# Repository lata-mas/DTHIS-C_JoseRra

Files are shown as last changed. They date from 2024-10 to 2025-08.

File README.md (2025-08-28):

# DTHIS-C

Este dispositivo se realizó gracias al apoyo del proyecto UNAM-PAPIIT IT103023.

El **DTHIS-C** (Dispositivo de Temperatura, Humedad, Iluminación y Sonido de Campaña) está diseñado para medir y evaluar condiciones ambientales tanto en interiores como en exteriores. Su principal ventaja es su portabilidad y su capacidad para adquirir y almacenar datos, haciéndolo ideal para campañas en sitios remotos o situaciones que requieren movilidad.

## Variables que mide el DTHIS-C

El dispositivo está equipado para medir una amplia gama de variables, tales como:

- **Temperatura del aire** a diferentes alturas:
  1. 0.1 m
  2. 0.6 m
  3. 1.1 m
  4. 1.7 m
- **Temperatura radiante**
- **Humedad relativa**
- **Velocidad del viento**
- **Concentración de CO₂**
- **Mapas de luminancia** para evaluar la iluminación
- **Deslumbramiento**
- **Niveles de sonido**

---

## Composición del DTHIS-C

El dispositivo se compone de los siguientes sensores y componentes electrónicos:

| **Sensor** | **Variable** | **Cantidad** | **Comunicación** | **Microcontrolador** | **Acondicionador de señal**  |
|---|---|---|---|---|---|
| Termopar tipo T | Temperatura Ambiente | 4 | SPI | Arduino UNO WiFi Rev2 | PWFusion SEN-30007 MAX31856	 |
| TPF1/E-20 PT1000 | Temperatura Radiante | 1 | SPI | Arduino UNO WiFi Rev2 | Adafruit PT1000 RTD-MAX31865 |
| Wind Sensor Rev P6 | Velocidad del Viento		 	 | 1 | ADC | Arduino UNO WiFi Rev2 |				 				 |
| SCD30 Sensirion | CO₂ y Humedad Relativa | 1 | I2C | Raspberry Pi 4 |				 				 |
| 5MP OV5647 Wide Angle Fisheye Camera | Luminancia | 1 | CSI | Raspberry Pi 4 |				 				 |
| Micrófono ambiental USB | Sonido | 1 | USB | Raspberry Pi 4 | |

---

## Elementos del repositorio
 
-  #### En [**CAD**](https://github.com/lata-mas/DTHIS-C_JoseRra/tree/main/CAD) encuentra
	-  Planos CAD
	-  Archivos de diseño CAD
	-  Archivos STL para impresión 3D

 - #### En [**Diagramas**](https://github.com/lata-mas/DTHIS-C_JoseRra/tree/main/Diagramas) encuentra
	- Pictograma de conexión
	- Esquemático de conexión

 - #### En [**Manuales**](https://github.com/lata-mas/DTHIS-C_JoseRra/tree/main/Manuales) encuentra
	-  Manual de operación
   	-  Fichas técnicas o datasheet de los sensores y componentes utilizados

 -  #### En [**Materiales**](https://github.com/lata-mas/DTHIS-C_JoseRra/tree/main/Materiales) encuentra
	-  Lista de materiales y costos

 -  #### En [**Scripts**](https://github.com/lata-mas/DTHIS-C_JoseRra/tree/main/Scripts) encuentra
	- Códigos completos y documentados
	- Librerías a utilizar

---

## Participantes del proyecto

El equipo responsable del desarrollo y construcción del DTHIS-C está conformado por los siguientes integrantes:

| **Nombre** | **Instituto/Organización** | **Email** |
|---|---|---|
| Guillermo Barrios del Valle  | IER-UNAM | gbv@ier.unam.mx |
| Guillermo Ramírez Zúñiga | IER-UNAM | guraz@ier.unam.mx |
| Jorge Luis Méndez Reyna | IER-UNAM | merejo@ier.unam.mx |
| Julio César Landa López | IER-UNAM | jclalo@ier.unam.mx |
| José Ramón Hernández Aguilar | IER-UNAM | jrha@ier.unam.mx |
| Pedro Ayala Espinosa	 | IER-UNAM | aepe@ier.unam.mx |
| Debra Paola López Domínguez  | | dpld@ier.unam.mx |
| Edgar Gallardo Pérez | | |
| José William Escobar Escobar | | |

---

> [!Tip]
> Este repositorio está diseñado para simplificar el desarrollo y uso del dispositivo **DTHIS-C**. Con su uso, podrás acceder a múltiples recursos clave para su implementación y operación eficiente:

### 1. Uso de sensores
Cada sensor integrado en el DTHIS-C tiene su propio directorio en el repositorio, dentro de los cuales encontrarás:
- **Indicaciones** para una correcta implementación.
- **Código funcional** específico para cada sensor.

### 2. Integración con ThingsBoard
El repositorio incluye un archivo **main** que recopila las mediciones de todos los sensores y las envía a la plataforma **ThingsBoard** mediante el protocolo **MQTT**. Esto permite la monitorización en tiempo real de las variables.

### 3. Manual de uso y ensamblaje
Además, el repositorio ofrece un manual detallado que cubre:
- **Esquemas de conexión** y **diagramas eléctricos**.
- **Instrucciones paso a paso** para el ensamblaje del DTHIS-C.
 
Este repositorio es útil tanto para trabajar con sensores de forma individual como para la construcción completa del dispositivo DTHIS-C.

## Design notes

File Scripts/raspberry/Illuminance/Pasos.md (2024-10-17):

# Configuración de la cámara en Raspberry Pi 4 y captura de fotos

### 1. Conectar la cámara
- Apaga la Raspberry Pi.
- Conecta la cámara al puerto CSI.
- Asegúrate de que la cinta esté bien conectada, con la parte metálica hacia el conector del puerto.

### 2. Actualizar el sistema
```bash
sudo apt update && sudo apt upgrade
```

### 3. Reiniciar Raspberry Pi
```bash
sudo reboot
```

### 4. Tomar una foto
```bash
rpicam-still -o imagen.jpg
```

---

# Instalación de Radiance 

### 1. Instala las dependencias necesarias:
```bash
sudo apt install csh make gcc g++ libx11-dev tcl tk
```

### 2. Descarga Radiance y el soporte adicional:
```bash
wget https://www.radiance-online.org/software/snapshots/radiance-HEAD.tgz
wget https://www.radiance-online.org/download-install/radiance-source-code/latest-release/rad5R4supp.tar.gz
```

### 3. Descarga `config.guess` y `config.sub`:
```bash
wget -O config.guess 'http://git.savannah.gnu.org/gitweb/?p=config.git;a=blob_plain;f=config.guess;hb=HEAD'
wget -O config.sub 'http://git.savannah.gnu.org/gitweb/?p=config.git;a=blob_plain;f=config.sub;hb=HEAD'
```

### 4. Descomprime los archivos descargados:
```bash
tar -xvzf radiance-HEAD.tgz
tar -xvzf rad5R4supp.tar.gz
```

### 5. Copia `config.sub` y `config.guess` al directorio `px/tiff/`:
```bash
cp config.sub ray/src/px/tiff/
cp config.guess ray/src/px/tiff/
```

### 6. Entra en el directorio `ray/` y compila la librería:
```bash
cd ray/
sudo ./makeall library
```
- Cuando se pregunte **"Where do you want the library files [/usr/local/lib/ray]?"**, puedes presionar `Enter` para aceptar la ruta predeterminada. Luego, cuando te pregunte **"Install library files now [n]?"**, responde `y` (sí).

### 7. Agrega la siguiente línea al archivo `.profile` para configurar el `RAYPATH`:
Abre el archivo `.profile`:
```bash
nano ~/.profile
```
Agrega las siguientes líneas al final del archivo:
```bash
RAYPATH=.:/usr/local/lib/ray
export RAYPATH
```
Guarda y cierra el archivo presionando `Ctrl + O`, `Enter`, y luego `Ctrl + X`.

### 8. Compila todo el proyecto:
Ejecuta el siguiente comando:
```bash
sudo ./makeall install
```
- Cuando te pregunte **"What is your preferred editor [vi]?"**, puedes simplemente presionar `Enter` para aceptar la opción predeterminada (vi)
- Cuando se te pregunte **"Where do you want the executables [/usr/local/bin]?"**, presiona `Enter` para aceptar la ruta predeterminada.
- Tras haber presionado `Enter` se mostrará la licencia de software de Radiance, presiona `q` para salir de la visualización y luego responde `y` (sí) para aceptar los términos. Selecciona `2` para Linux cuando se te pregunte por el tipo de sistema.
- Cuando se te pregunte **"Do you want to change it?"**, presiona `n` (no) para continuar con la configuración predeterminada.

### 9. Verifica la instalación:
Para asegurarte de que Radiance se haya instalado correctamente, ejecuta:
```bash
which rad
```
Esto debería devolver la ruta del ejecutable rad si la instalación fue exitosa.

---

# Configuración adicional

### 1. Instalar raw2hdr 
Descarga el software *raw2hdr* desde [aquí](http://www.anyhere.com/gward/pickup/raw2hdr.tgz) (debería descargarse si arrastras el enlace hacia otra pestaña). 
- Descomprime el archivo descargado con el siguiente comando, aunque igualmente puedes descomprimirlo sin la necesidad de acudir a la terminal:
  ```bash
  tar -xvzf raw2hdr.tgz
  ```
- Tras ello se creará la carpeta `raw2hdr` en tu **home** con los siguientes archivos ejecutables:
  - dcraw (Descartar)
  - exiftool (Descartar)
  - hdrgen (Descartar)
  - raw2hdr
- Para que raw2hdr funcione con imágenes DNG, accede al archivo ejecutable `raw2hdr` y agrega lo siguiente a la configuración del array `@exiftags` :
  ```bash
  -ISO -ApertureValue>FNumber -FNumber=2.6
  ```
- Finalmente para utilizar los comandos de los programas desde cualquier ubicación, los archivos ejecutables deben encontrarse en `/usr/local/bin/`:
  ```bash
  sudo cp exiftool raw2hdr /usr/local/bin/
  ```

### 2. Es necesario instalar los programas `hdrgen`, `dcraw` y `exiftool` para que `raw2hdr` se pueda compilar correctamente.  

#### hdrgen 
Puedes descargar *hdrgen* desde [aquí](http://anyhere.com/gward/pickup/hdrgen_AMDRaspian.tar.gz) (al arrastrar el enlace a otra pestaña se inicia la descarga).  
- Descomprime el archivo descargado preferentemente sin acudir a la terminal.
- Tras ello se creará la carpeta `hdrgen_AMDRaspian` en tu **home** con los siguientes archivos ejecutables:
  - hdrcvt
  - hdrgen
- Copia los archivos ejecutables hacia `/usr/local/bin/`:
  ```bash
  sudo cp hdrcvt hdrgen /usr/local/bin/
  ```

#### dcraw
Para instalar *dcraw*, asegúrate de ejecutar el comando:
```bash
sudo apt-get install dcraw
```

#### exiftool
Para descargar *exiftool*, ejecuta la siguiente línea:
```bash
wget https://exiftool.org/Image-ExifTool-12.97.tar.gz
```
- Una vez descargado, descomprime el archivo y accede al directorio:
  ```bash
  gzip -dc Image-ExifTool-12.97.tar.gz | tar -xf -
  cd Image-ExifTool-12.97
  ```
- Procede a instalarlo:
  ```bash
  perl Makefile.PL
  sudo make install
  ```

### 3. Instalar bibliotecas de fuentes para visualizar imágenes
Finalmente, necesitas descargar una biblioteca de fuentes para poder visualizar las imágenes. Si no tienes las fuentes instaladas, usa el siguiente comando:
```bash
sudo apt-get install xfonts*
```

---

# Creación de un script de shell con vim

### 1. Abre `vim` y crea un nuevo archivo de script:
```bash
vim script.sh
```

### 2. Entra en el **modo de inserción** presionando la tecla `i`.

### 3. Escribe el contenido del script:
```bash
#!/bin/bash
echo "Hola, este es mi primer script!"
```

### 4. Una vez que hayas terminado de escribir el script, presiona `Esc` para salir del **modo de inserción**.

### 5. Guarda el archivo y sal de `vim` escribiendo `:wq` y presionando `Enter`. Esto significa:
- `w` para guardar el archivo.
- `q` para salir de `vim`.

### 6. Haz el script ejecutable con el siguiente comando:
```bash
chmod +x script.sh
```

### 7. Ejecuta el script:
```bash
./script.sh
```

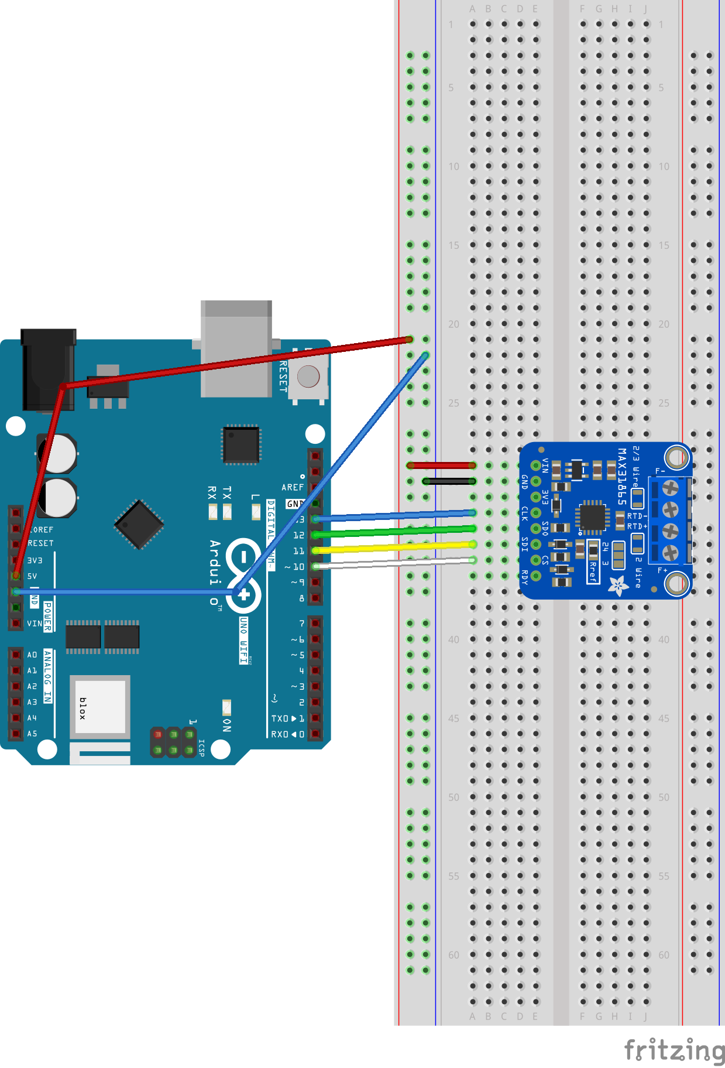
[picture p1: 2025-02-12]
Diagramas/Pictogramas/pt1000_bb.png

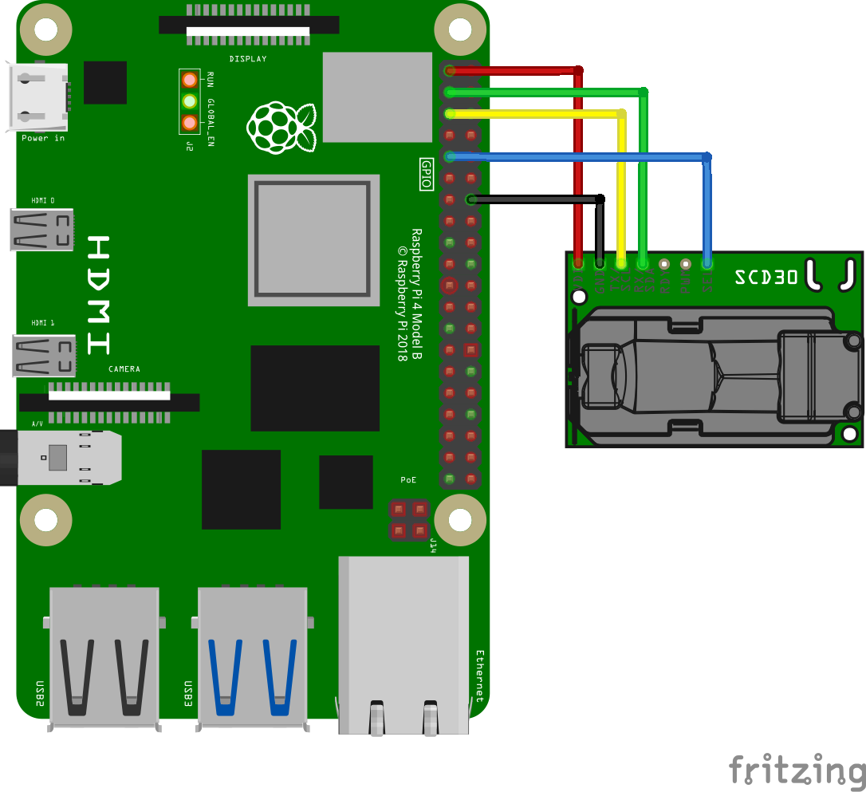
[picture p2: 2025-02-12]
Diagramas/Pictogramas/scd30_bb.png

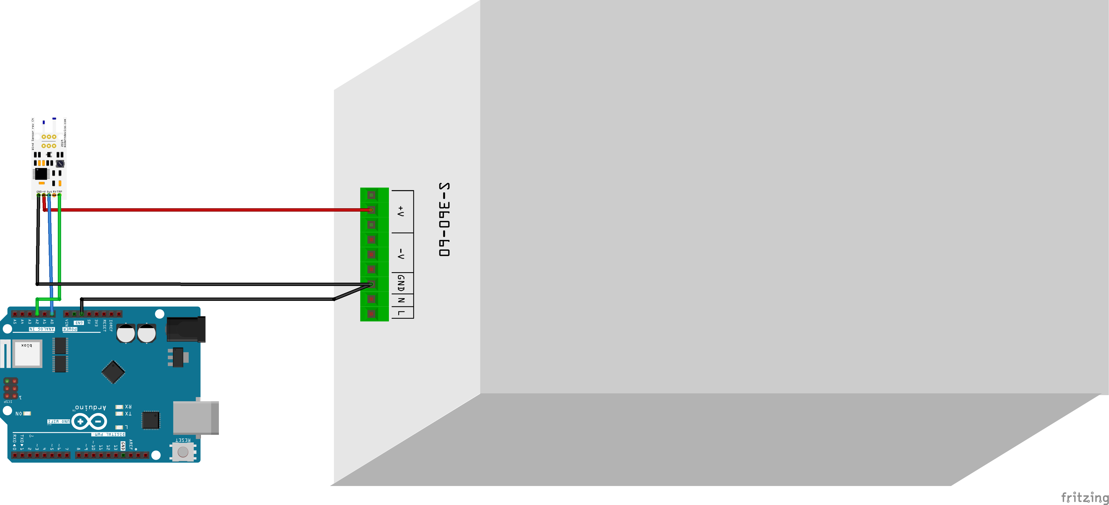
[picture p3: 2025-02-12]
Diagramas/Pictogramas/windsensor_bb.png

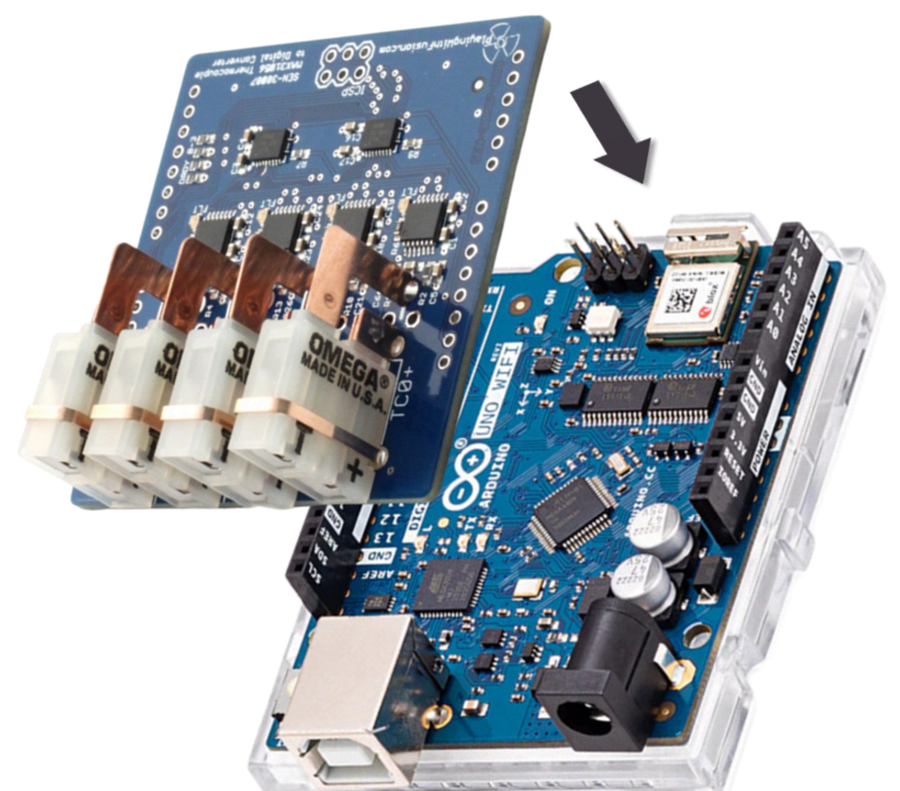
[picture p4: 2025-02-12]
Diagramas/Pictogramas/sen30007_bb.png

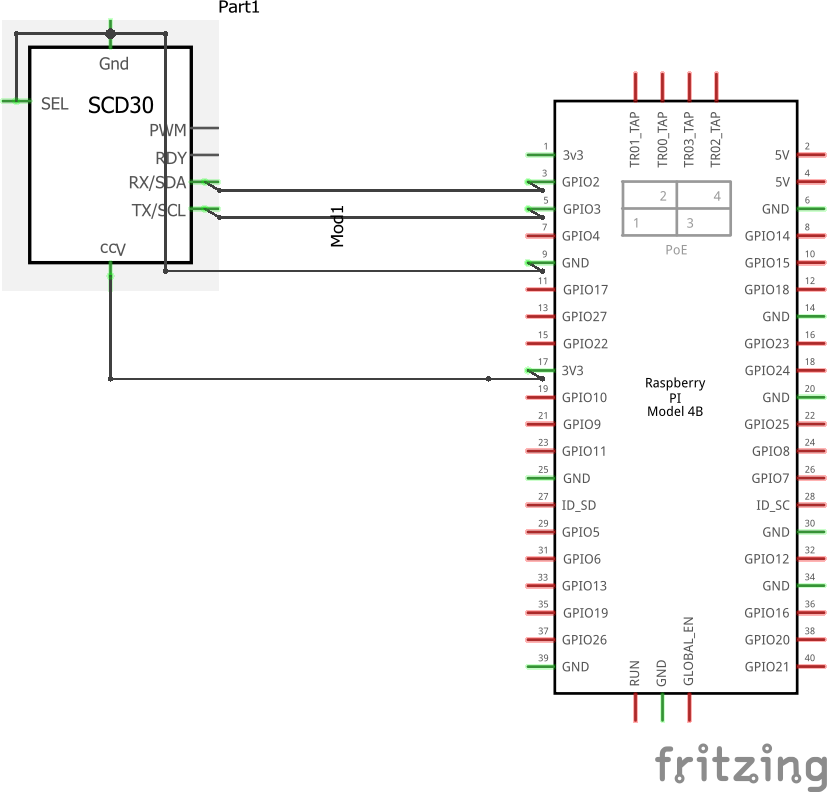
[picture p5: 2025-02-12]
Diagramas/Esquematicos/scd30_esquematico.png

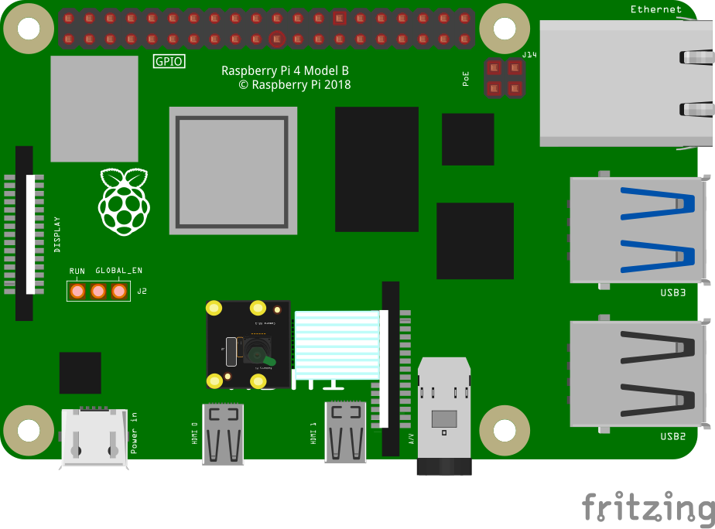
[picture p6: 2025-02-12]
Diagramas/Pictogramas/camera_bb.png

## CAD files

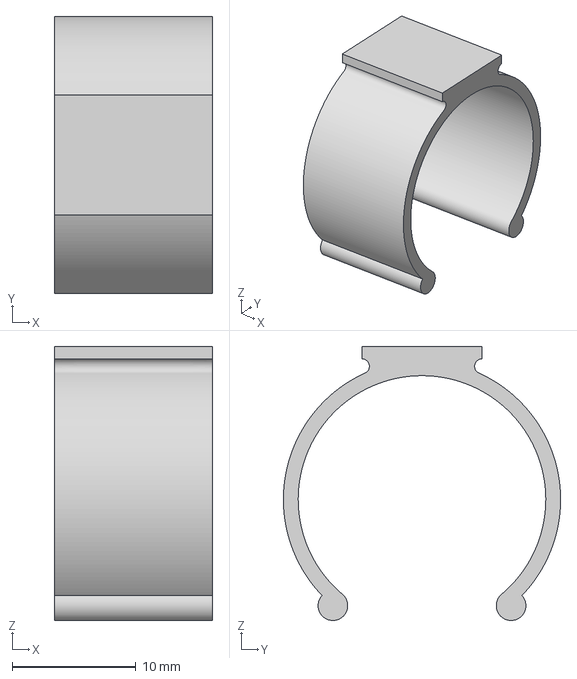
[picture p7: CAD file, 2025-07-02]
CAD/3MF/Wind_Sensor/WS_Ring_Horizontal_3cuartes_inch.3mf
12.8 x 22.4 x 22.1 mm

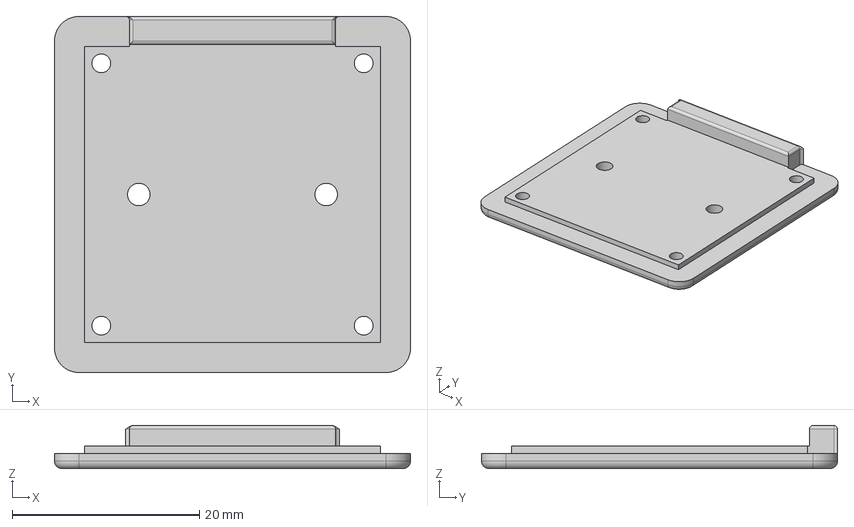
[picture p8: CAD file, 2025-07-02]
CAD/STEP/Camera/Camera_Cover.step
38.0 x 38.0 x 4.60 mm
Camera
Cam_Case
Cam_Cover

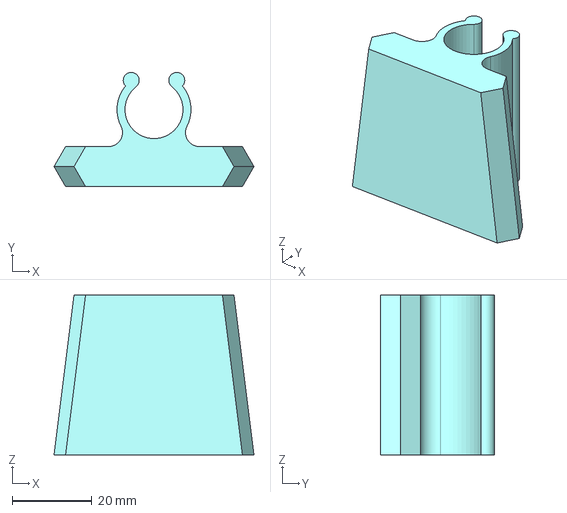
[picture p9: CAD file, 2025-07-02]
CAD/STEP/Case/Ring_Bottom.step
50.0 x 28.5 x 40.0 mm

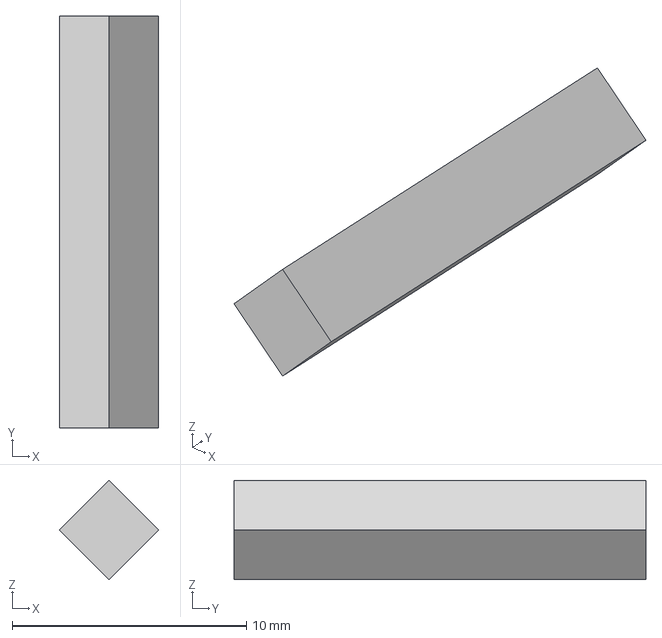
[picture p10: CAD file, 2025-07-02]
CAD/STEP/Power_Supply_Case/4xPowerSupply_Pin.step
4.24 x 17.6 x 4.24 mm

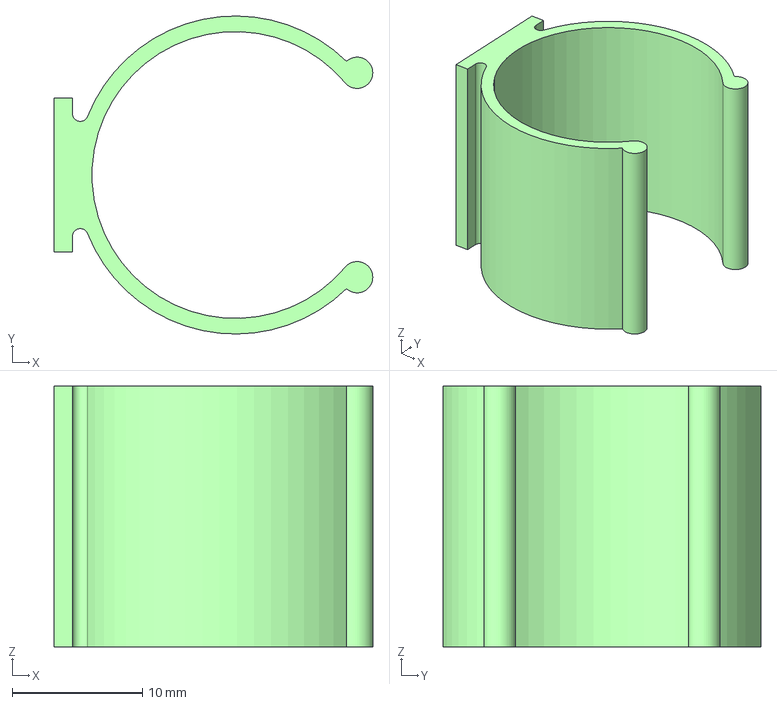
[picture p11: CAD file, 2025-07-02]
CAD/STEP/TRad/Ring_Vertical_TRad_3quarters_inch.step
24.4 x 24.4 x 20.0 mm

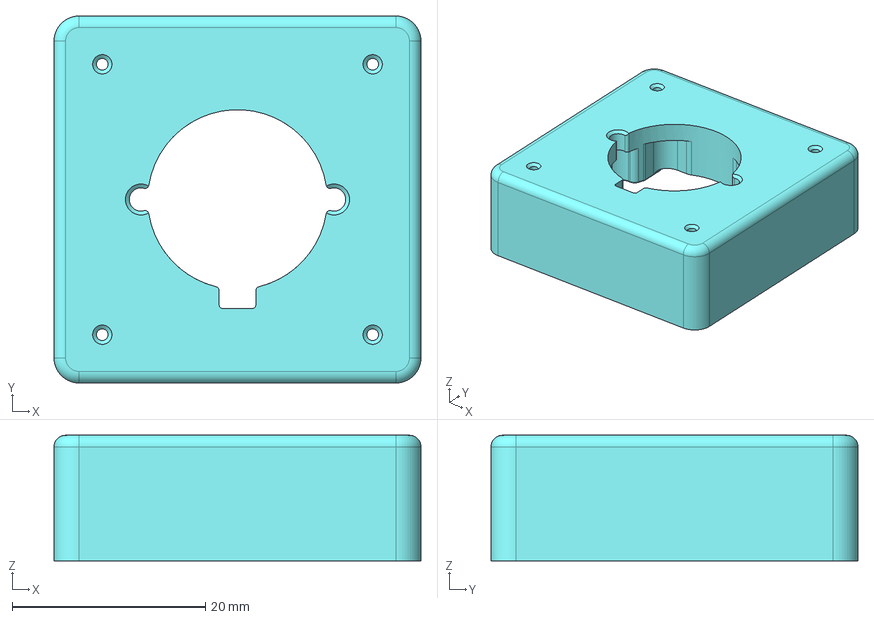
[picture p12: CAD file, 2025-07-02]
CAD/STEP/Camera/Camera_Case.step
38.0 x 38.0 x 13.0 mm
Camera
Cam_Case
Cam_Cover

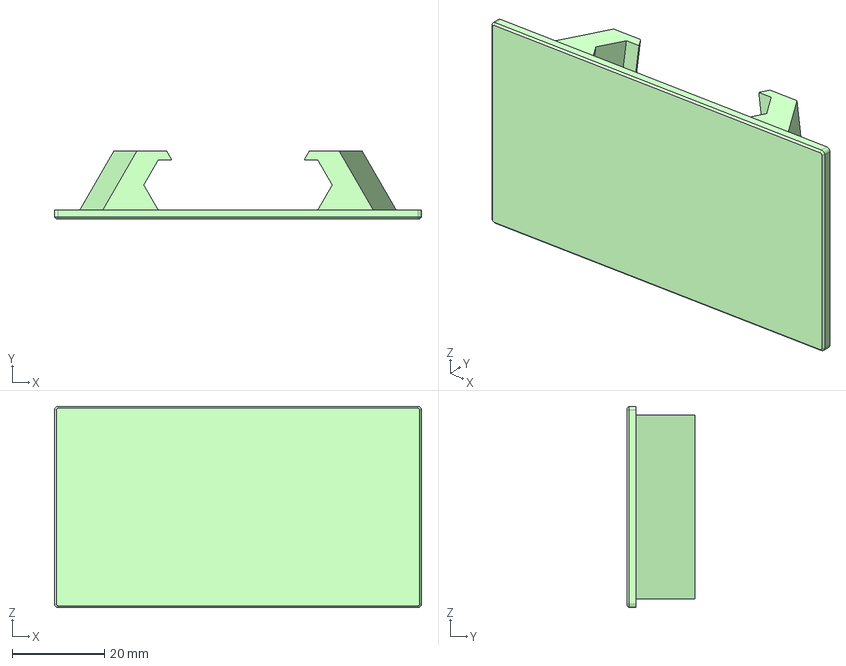
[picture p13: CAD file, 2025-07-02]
CAD/STEP/Case/Hook_Bottom.step
79.7 x 14.8 x 43.7 mm

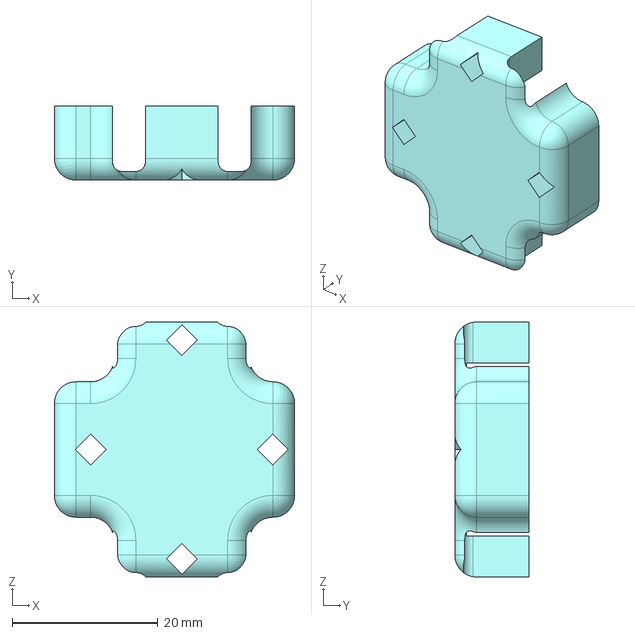
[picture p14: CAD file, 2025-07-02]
CAD/STEP/Power_Supply_Case/PowerSupply_Cover.step
33.0 x 10.2 x 35.0 mm

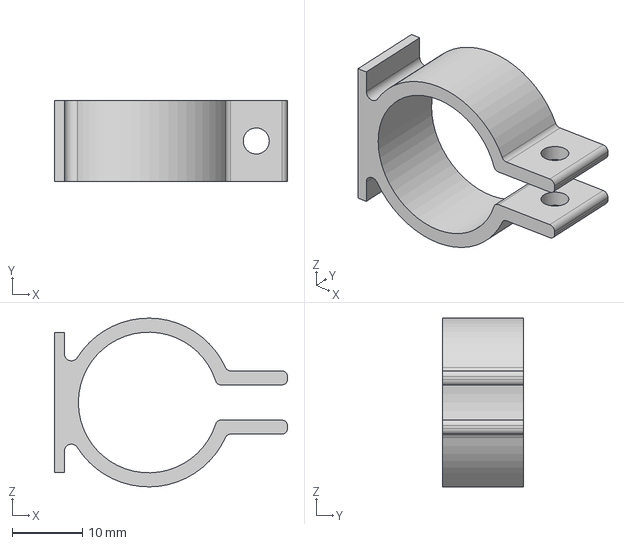
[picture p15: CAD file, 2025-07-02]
CAD/STEP/TRad/Ring_Horizontal_TRad_3quarters_inch.step
33.1 x 11.5 x 24.0 mm

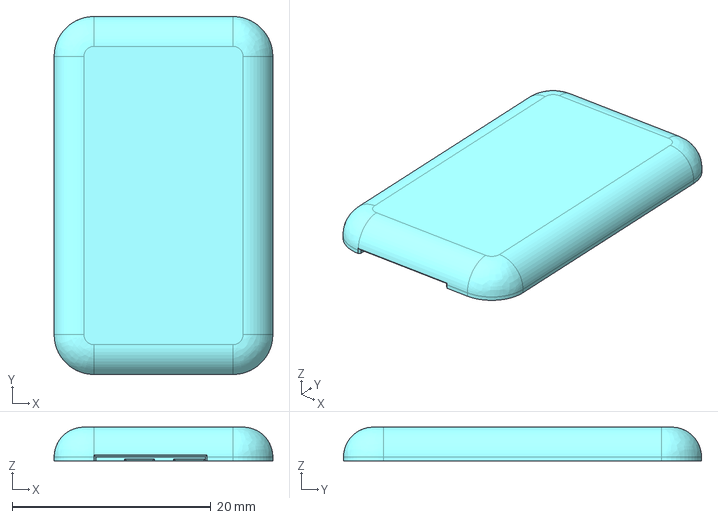
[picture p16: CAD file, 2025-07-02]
CAD/STEP/Wind_Sensor/WS_Cover.step
22.0 x 36.0 x 3.40 mm

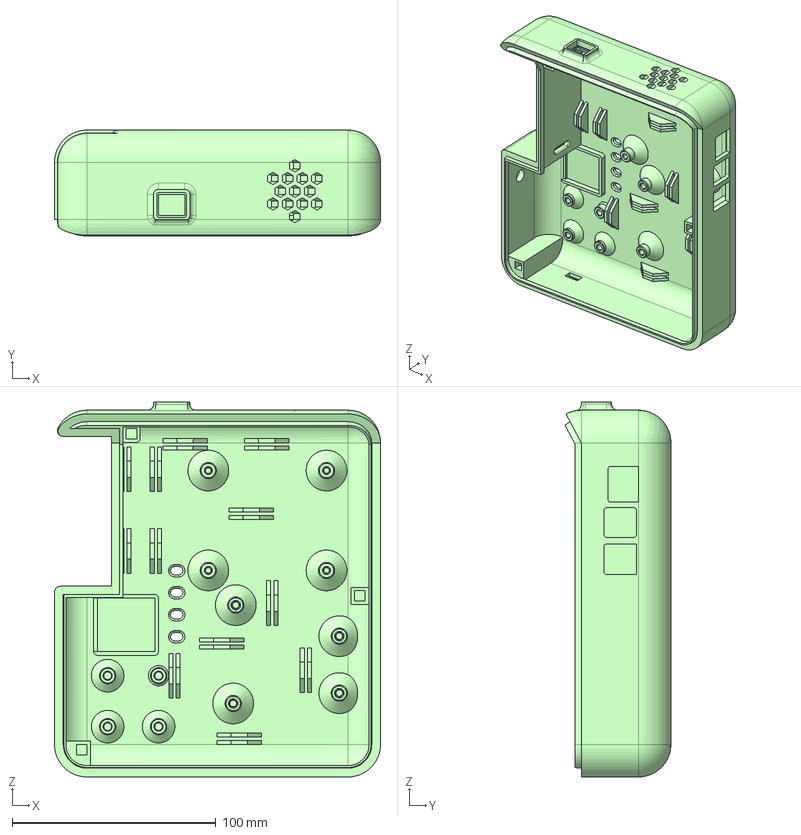
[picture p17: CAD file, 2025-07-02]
CAD/STEP/Case/Case.step
160.0 x 52.0 x 184.0 mm

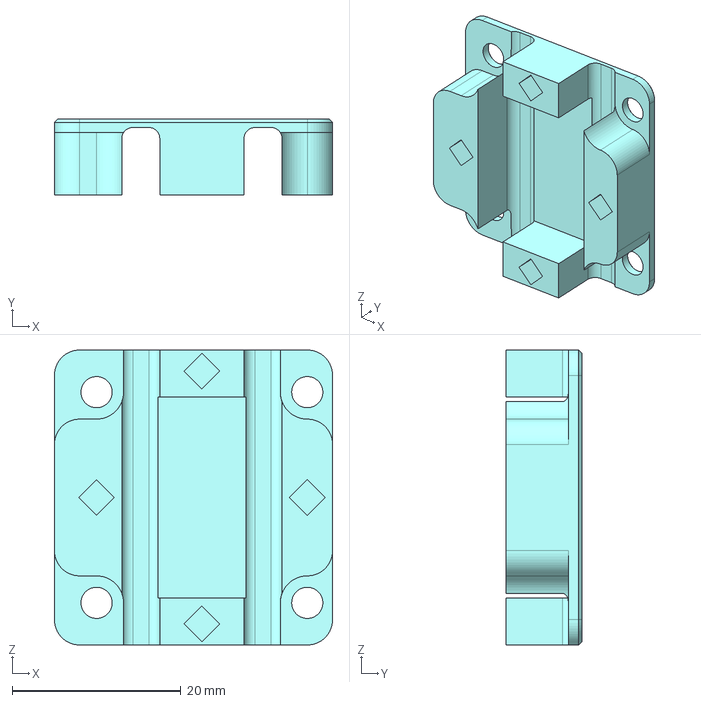
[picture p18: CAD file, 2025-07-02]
CAD/STEP/Power_Supply_Case/Power_Supply_Case.step
33.0 x 9.00 x 35.0 mm

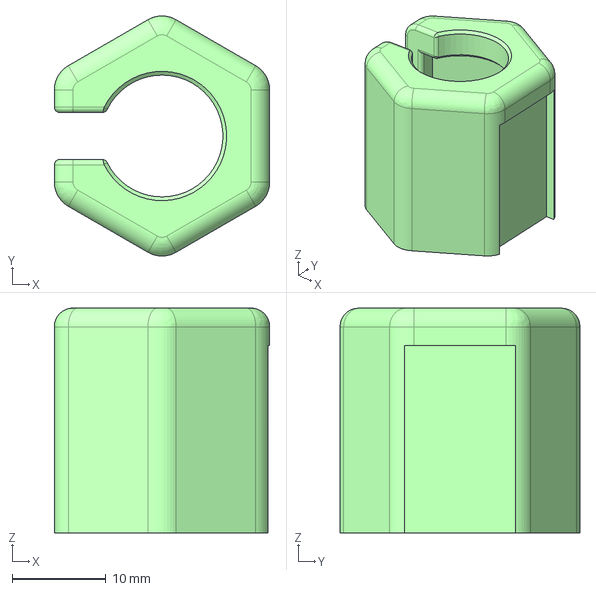
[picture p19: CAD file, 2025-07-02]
CAD/STEP/TRad/TRad_Support.step
23.0 x 25.6 x 24.0 mm

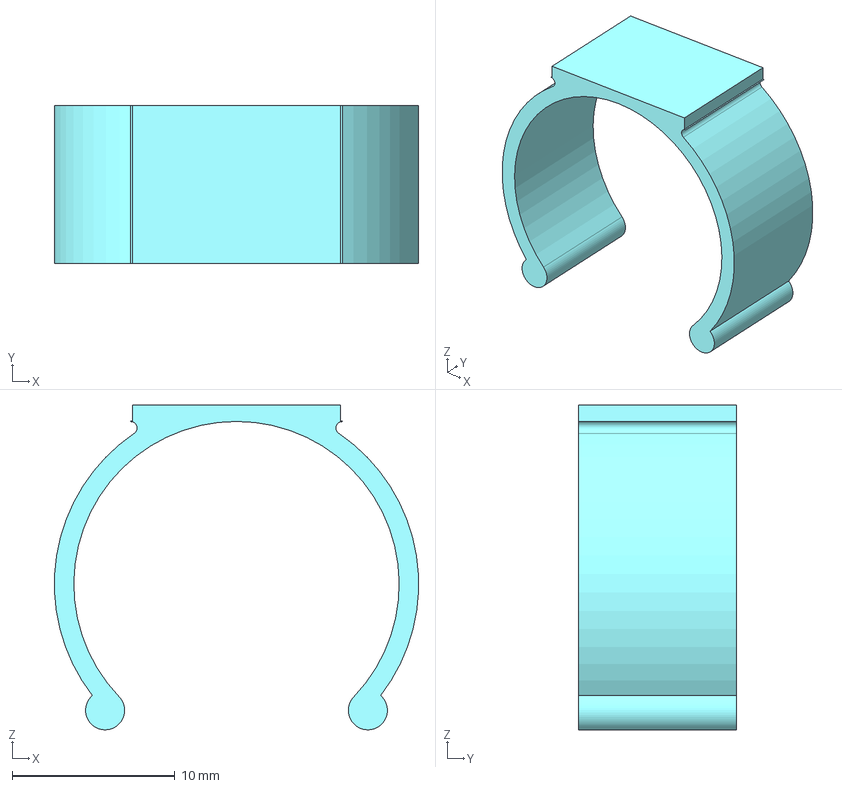
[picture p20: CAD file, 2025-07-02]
CAD/STEP/Wind_Sensor/WS_Ring_Vertical_3quarters_inch.step
22.4 x 9.70 x 20.0 mm

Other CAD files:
CAD/STEP/Wind_Sensor/WS_Ring_Horizontal_3quarters_inch.step
CAD/STEP/Case/Ring_Top.step
CAD/STEP/Wind_Sensor/WS_Case.step
CAD/STEP/Case/Cover.step
CAD/3MF/Camera/Camera_Case.3mf
CAD/3MF/Camera/Camera_Cover.3mf
CAD/3MF/Case/Case.3mf
CAD/3MF/Case/Cover.3mf
CAD/3MF/Case/Hook_Bottom.3mf
CAD/3MF/Case/Hook_Top.3mf
CAD/3MF/Case/Ring_Bottom.3mf
CAD/3MF/Case/Ring_Top.3mf
CAD/3MF/Power_Supply_Case/4xPowerSupply_Pin.3mf
CAD/3MF/Power_Supply_Case/PowerSupply_Case.3mf
CAD/3MF/Power_Supply_Case/PowerSupply_Cover.3mf
CAD/3MF/TRad/Ring_Horizontal_TRad_3quarters_inch.3mf
CAD/3MF/TRad/Ring_Vertical_TRad_3quarters_inch.3mf
CAD/3MF/TRad/TRad_Support.3mf
CAD/3MF/Wind_Sensor/WS_Case.3mf
CAD/3MF/Wind_Sensor/WS_Cover.3mf
CAD/3MF/Wind_Sensor/WS_Ring_Vertical_3quarters_inch.3mf
CAD/STEP/Case/Hook_Top.step
CAD/STL/Camera/Camera_Case.stl
CAD/STL/Camera/Camera_Cover.stl
CAD/STL/Case/Case.stl
CAD/STL/Case/Cover.stl
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

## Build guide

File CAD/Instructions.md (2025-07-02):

## Instructions to print the pieces

- Set the pieces flat whenever possible (print hooks and case rings as they are).  
- Infill of 10% gyroid or cubic and 4 perimeters are recommended for fast processing times.  
- Printing with UV‑resistant filament is recommended (ASA).  

---

## List of extra hardware required for mounting and power supply

### Electronic hardware

- 1 × 10 W 5 V DC buck converter  
- 2 × banana plug binding post socket  
- 1 × XT30 female connector  
- 1 × 4‑channel 5‑pin perfboard  
- 4 × 5 × 2.54 mm pin headers  
- 1 × 5 V fan  

---

## Mounting hardware

### SCD30

- 4 × 10 mm M2 nylon standoffs  
- 4 × M2 × 6 mm nylon screws  
- 4 × M2 × 3 mm brass inserts  

### Raspberry Pi 4

- 4 × M2 × 6 mm brass inserts  
- 4 × M2 × 6 mm nylon screws  

### Arduino Uno

- 4 × 6 mm M3 nylon standoffs  
- 4 × M3 × 6 mm nylon screws  
- 4 × M3 × 6 mm brass inserts  

### Fan

- 4 × M3 × 4 mm brass inserts  
- 4 × M3 × 8 mm screws  

### Thermocouple

- 2 × M2 × 3 mm brass inserts  
- 2 × M2 × 4 mm nylon standoffs  
- 2 × M2 × 6 mm screws  

### Power supply

- 4 × M3 × 6 mm brass inserts  
- 4 × M3 × 6 mm nylon screws  

### Magnets

- 6 × 5 mm × 5 mm × 5 mm N52 neodymium magnets  

*Created at IER‑UNAM by Joserra & Aerofal (2025)*

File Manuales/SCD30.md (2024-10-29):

# Configuración del SCD30 en Raspberry Pi 4

### 1. Ensamblar el circuito
Para la conexión del sensor SCD30, se requiere una Raspberry Pi 4 Model B y los cables de conexión (jumpers) incluidos con el sensor, que permiten la conexión directa al microcontrolador. Las conexiones deben realizarse de acuerdo con el siguiente diagrama:
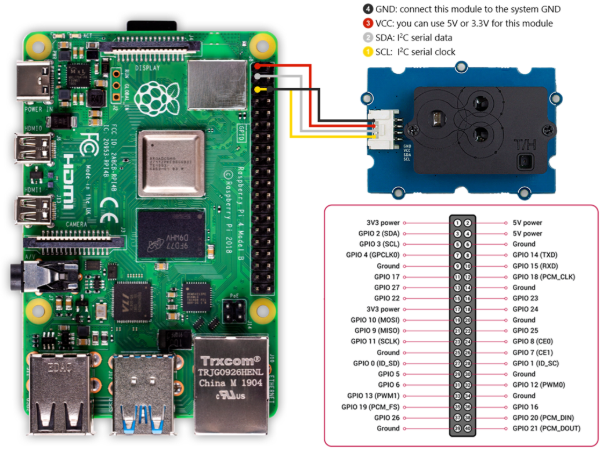
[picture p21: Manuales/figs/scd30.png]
SCD30


### 2. Crear script de Python
El script [scd30.py](https://github.com/lata-mas/DTHIS-C_JoseRra/blob/main/Scripts/Raspberry/scd30.py) inicializa el sensor `SCD30` y obtiene lecturas de la `concentración de CO2`, `temperatura` y `humedad relativa` para devolverlos como una tupla (CO2, T, HR) al final.

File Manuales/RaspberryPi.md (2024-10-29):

# Configuración general de la Raspberry Pi 4

### 1. Habilitar comunicaciones 
Antes de tratar de inicializar cualquier tipo de sensor, se deberán habilitar las siguientes comuncionaciones:
- SPI
- I2C
- Serial Port
- 1-Wire

Para acceder a la configuración, se debe ejecutar el siguiente comando en la terminal:
```bash
sudo raspi-config
```
1. Dentro del menú, es necesario dirigirse al apartado `Interface Options`.
2. Habilitar uno por uno: **SPI**, **I2C**, **Serial Port**, **1-Wire**.
3. Al finalizar se reiniciará la Raspberry.

### 2. Crear un ambiente virtual
Dentro de la terminal, se creará un directorio que albergue los ambientes virtuales, así mismo dentro de dicho folder, se creará el ambiente ejecutando las siguientes líneas:
```bash
mkdir venvs
cd venvs
python -m venv dthis-c
```

Tras haberse creado, debe activarse con el siguiente comando:
```bash
source venvs/dthis-c/bin/activate
```

### 3. Instalar bibliotecas 
Las bibliotecas necesarias para ejecutar los scripts de Python de cada sensor que forma parte del DTHIS-C se pueden obtener instalando el archivo [requirements.txt](https://github.com/lata-mas/DTHIS-C_JoseRra/blob/main/Scripts/Raspberry/requirements.txt) dentro del entorno virtual.

1. Activa el entorno virtual:
```bash
source venvs/dthis-c/bin/activate
```
2. Instala las dependencias desde el archivo `requirements.txt`:
```bash
python -m pip install -r requirements.txt
```

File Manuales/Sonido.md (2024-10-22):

# Configuración del micrófono en Raspberry Pi 4

### 1. Conectar el micrófono
- Apaga la Raspberry Pi.
- Conecta el micrófono a un puerto USB.

### 2. Instalar paqueterías
```bash
sudo apt update
sudo apt install alsa-utils
sudo apt install sox libsox-fmt-all
```

### 3. Comprobar micrófono
Para identificar a que puerto está conectado el micrófono, ejecuta el siguiente comando:
```bash
arecord -l
```
Se desplegará lo siguiente:

Terminal

En este caso `card 3` es el puerto al que está conectado el micrófono, por lo tanto al ejecutar el comando para la captura de audio, se deberá definir `plughw:3,0`.

### 4. Grabar audio
Para grabar un audio se ejecuta el siguiente comando:
```bash
arecord -D plughw:3,0 -f cd -t wav -d 15 -r 44100 audio.wav
```

---

# Creación de un programa para la obtención de datos de los audios

### 1. Crear scripts acorde a las funciones 
- [grabar.sh](https://github.com/lata-mas/DTHIS-C_JoseRra/blob/main/Scripts/Raspberry/Sonido/grabar.sh): Graba 15 segundos de audio en calidad CD. 
- [dBmax.sh](https://github.com/lata-mas/DTHIS-C_JoseRra/blob/main/Scripts/Raspberry/Sonido/dBmax.sh): Extrae la amplitud máxima del archivo de audio.
- [dBmin.sh](https://github.com/lata-mas/DTHIS-C_JoseRra/blob/main/Scripts/Raspberry/Sonido/dBmin.sh): Extrae la amplitud mínima del archivo de audio.
- [rms.sh](https://github.com/lata-mas/DTHIS-C_JoseRra/blob/main/Scripts/Raspberry/Sonido/rms.sh): Extrae la amplitud RMS, una medida de la potencia promedio del audio.

### 2. Crear un ejecutable para correr todos los scripts
Para evitar que la Raspberry Pi falle por sobrecarga de procesos, se creará un archivo ejecutable `.e` que ejecutará los scripts secuencialmente, asegurando que no haya conflictos entre las instrucciones. Es fundamental especificar la ruta completa del directorio y activar el entorno virtual antes de ejecutar el script que envía la información a ThingsBoard. 

El archivo se crea de la siguiente manera:
```bash
vim executable.e
```

Y su contenido debe ser el siguiente:
```bash
/home/hdeza/Sonido/grabar.sh
/home/hdeza/Sonido/dBmax.sh
/home/hdeza/Sonido/dBmin.sh
/home/hdeza/Sonido/rms.sh
/home/hdeza/venvs/dthis-c/bin/python3 /home/hdeza/dthis/scripts/sound.py
```

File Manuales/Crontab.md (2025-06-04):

# Configuración de crontab en Raspberry Pi

Para automatizar la ejecución periódica de los scripts del DTHIS-C, se utiliza `cron` y el archivo `crontab`. A continuación se describe el proceso de configuración paso a paso.

---

### 1. Hacer los scripts ejecutables

Antes de agendar cualquier tarea en `crontab`, asegúrate de que todos los archivos que deben ejecutarse directamente tengan permisos de ejecución. Por ejemplo, desde la terminal de tu Raspberry Pi:

```bash
chmod +x /home/dthisc/dthis-c/scd30.py
chmod +x /home/dthisc/dthis-c/sound/executable.e
chmod +x /home/dthisc/dthis-c/sonido.py
chmod +x /home/dthisc/dthis-c/illuminance/createHDR.sh
chmod +x /home/dthisc/dthis-c/iluminancia.py
```

### 2. Verificar el contenido actual de crontab

Para revisar las entradas existentes en el crontab del usuario, ejecuta:

```bash
crontab -l
```

### 3. Editar el crontab
Para agregar o modificar las tareas programadas, abre el editor de crontab:

```bash
crontab -e
```

En el editor que se abra (normalmente nano o vim), pega las siguientes líneas al final del archivo:

```bash
# Ejecutar scd30.py cada minuto
* * * * * /bin/bash -c 'source /home/dthisc/venvs/dthisc/bin/activate && /home/dthisc/venvs/dthisc/bin/python3 /home/dthisc/dthis-c/scd30.py' >> /home/dthisc/dthis-c/scd30.log 2>&1

# Ejecutar sonido (ejecutable) cada 2 minutos
*/2 * * * * /home/dthisc/dthis-c/sound/executable.e >> /home/dthisc/dthis-c/sound/errores_e.log 2>&1

# Ejecutar sonido.py cada 2 minutos
*/2 * * * * /bin/bash -c 'source /home/dthisc/venvs/dthisc/bin/activate && /home/dthisc/venvs/dthisc/bin/python3 /home/dthisc/dthis-c/sonido.py' >> /home/dthisc/dthis-c/sonido.log 2>&1

# Ejecutar createHDR.sh cada 30 minutos
*/30 * * * * /home/dthisc/dthis-c/illuminance/createHDR.sh >> /home/dthisc/dthis-c/illuminance/createHDR.log 2>&1

# Ejecutar iluminancia.py cada 30 minutos
*/30 * * * * /bin/bash -c 'source /home/dthisc/venvs/dthisc/bin/activate && /home/dthisc/venvs/dthisc/bin/python3 /home/dthisc/dthis-c/iluminancia.py' >> /home/dthisc/dthis-c/iluminancia.log 2>&1
```

- Se usa >> `archivo.log 2>&1` para redirigir tanto la salida estándar como los errores a un archivo de log.

- En los comandos Python, se activa primero el entorno virtual (`venvs/dthisc`) para asegurar que se usen las dependencias correctas.

Guarda el archivo y cierra el editor (en `nano`: `Ctrl+O`, `Enter`, `Ctrl+X`; en `vim`: `:wq`).

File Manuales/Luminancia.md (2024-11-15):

# Configuración de la cámara en Raspberry Pi 4

### 1. Conectar la cámara
- Apaga la Raspberry Pi.
- Conecta la cámara al puerto CSI.
- Asegúrate de que la cinta esté bien conectada, con la parte metálica hacia el conector del puerto.

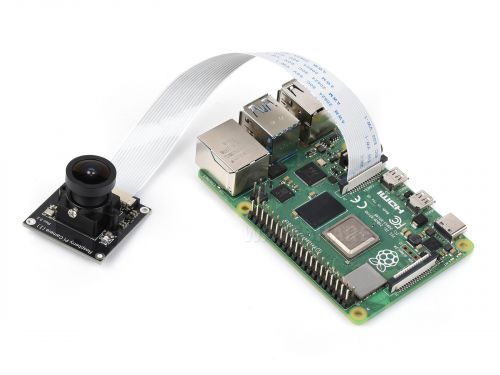
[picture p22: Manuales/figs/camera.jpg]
Camera


### 2. Actualizar el sistema
```bash
sudo apt update && sudo apt upgrade
```

### 3. Reiniciar Raspberry Pi
```bash
sudo reboot
```

### 4. Tomar una foto
```bash
rpicam-still -o imagen.jpg
```

---

# Instalación de Radiance 

### 1. Instalar dependencias
```bash
sudo apt install csh make gcc g++ libx11-dev tcl tk
```

### 2. Descargar Radiance y soporte adicional
```bash
wget https://www.radiance-online.org/software/snapshots/radiance-HEAD.tgz
wget https://www.radiance-online.org/download-install/radiance-source-code/latest-release/rad5R4supp.tar.gz
```

### 3. Descargar `config.guess` y `config.sub`
```bash
wget -O config.guess 'http://git.savannah.gnu.org/gitweb/?p=config.git;a=blob_plain;f=config.guess;hb=HEAD'
wget -O config.sub 'http://git.savannah.gnu.org/gitweb/?p=config.git;a=blob_plain;f=config.sub;hb=HEAD'
```

### 4. Descomprimir archivos
```bash
tar -xvzf radiance-HEAD.tgz
tar -xvzf rad5R4supp.tar.gz
```

### 5. Copiar `config.sub` y `config.guess`
```bash
cp config.sub ray/src/px/tiff/
cp config.guess ray/src/px/tiff/
```

### 6. Compilar librería
```bash
cd ray/
sudo ./makeall library
```
- Cuando se pregunte **"Where do you want the library files [/usr/local/lib/ray]?"**, puedes presionar `Enter` para aceptar la ruta predeterminada. Luego, cuando te pregunte **"Install library files now [n]?"**, responde `y` (sí).

### 7. Configurar `RAYPATH`
Abre el archivo `.profile`:
```bash
nano ~/.profile
```
Agrega las siguientes líneas al final del archivo:
```bash
RAYPATH=.:/usr/local/lib/ray
export RAYPATH
```
Guarda y cierra el archivo presionando `Ctrl + O`, `Enter`, y luego `Ctrl + X`.

### 8. Compilar proyecto
Ejecuta el siguiente comando:
```bash
sudo ./makeall install
```
- Cuando te pregunte **"What is your preferred editor [vi]?"**, puedes simplemente presionar `Enter` para aceptar la opción predeterminada (vi)
- Cuando se te pregunte **"Where do you want the executables [/usr/local/bin]?"**, presiona `Enter` para aceptar la ruta predeterminada.
- Tras haber presionado `Enter` se mostrará la licencia de software de Radiance, presiona `q` para salir de la visualización y luego responde `y` (sí) para aceptar los términos. Selecciona `2` para Linux cuando se te pregunte por el tipo de sistema.
- Cuando se te pregunte **"Do you want to change it?"**, presiona `n` (no) para continuar con la configuración predeterminada.

### 9. Verificar instalación
Para asegurarte de que Radiance se haya instalado correctamente, ejecuta:
```bash
which rad
```
Esto debería devolver la ruta del ejecutable rad si la instalación fue exitosa.

## Configuración adicional

### 1. Instalar raw2hdr 
Descarga el software `raw2hdr` desde [aquí](http://www.anyhere.com/gward/pickup/raw2hdr.tgz) (debería descargarse si arrastras el enlace hacia otra pestaña). 
- Descomprime el archivo descargado con el siguiente comando, aunque igualmente puedes descomprimirlo sin la necesidad de acudir a la terminal:
  ```bash
  tar -xvzf raw2hdr.tgz
  ```
- Tras ello se creará la carpeta `raw2hdr` en tu **home** con los siguientes archivos ejecutables:
  - dcraw (Descartar)
  - exiftool (Descartar)
  - hdrgen (Descartar)
  - raw2hdr
- Para que raw2hdr funcione con imágenes DNG, accede al archivo ejecutable `raw2hdr` y agrega lo siguiente a la configuración del array `@exiftags` :
  ```bash
  -ISO -ApertureValue>FNumber -FNumber=2.6
  ```
- Finalmente para utilizar los comandos de los programas desde cualquier ubicación, los archivos ejecutables deben encontrarse en `/usr/local/bin/`:
  ```bash
  sudo cp raw2hdr/raw2hdr /usr/local/bin/
  ```

### 2. Instalar programas necesarios  

#### hdrgen 
Puedes descargar *hdrgen* desde [aquí](http://anyhere.com/gward/pickup/hdrgen_AMDRaspian.tar.gz) (al arrastrar el enlace a otra pestaña se inicia la descarga).  
- Descomprime el archivo descargado preferentemente sin acudir a la terminal.
- Tras ello se creará la carpeta `hdrgen_AMDRaspian` en tu **home** con los siguientes archivos ejecutables:
  - hdrcvt
  - hdrgen
- Copia los archivos ejecutables hacia `/usr/local/bin/`:
  ```bash
  sudo cp hdrcvt hdrgen /usr/local/bin/
  ```

#### dcraw
Para instalar *dcraw*, asegúrate de ejecutar el comando:
```bash
sudo apt-get install dcraw
```

#### exiftool
Para descargar *exiftool*, ejecuta la siguiente línea:
```bash
wget https://exiftool.org/Image-ExifTool-12.97.tar.gz
```
- Una vez descargado, descomprime el archivo y accede al directorio:
  ```bash
  gzip -dc Image-ExifTool-12.97.tar.gz | tar -xf -
  cd Image-ExifTool-12.97
  ```
- Procede a instalarlo:
  ```bash
  perl Makefile.PL
  sudo make install
  ```

### 3. Instalar bibliotecas de fuentes
Finalmente, necesitas descargar una biblioteca de fuentes para poder visualizar las imágenes:
```bash
sudo apt-get install xfonts*
```

---

# Visualización de imágenes .hdr
Para visualizar alguna imagen formato `.hdr` generada tras haber ejecutado el script [createHDR.sh](https://github.com/lata-mas/DTHIS-C_JoseRra/blob/main/Scripts/Raspberry/createHDR.sh), es necesario instalar la biblioteca `imagemagick`:
```bash
sudo apt-get install imagemagick
```

Tras ello ejecuta el siguiente comando:
```bash
display /home/ruta/del/archivo/nombre.hdr
```

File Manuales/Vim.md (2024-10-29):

# Creación de un script de shell con Vim

### 1. Crear archivo de script
```bash
vim script.sh
```

### 2. Escribir contenido del script
Entra en el **modo de inserción** presionando la tecla `i`.
```bash
#!/bin/bash
echo "Hola, este es mi primer script!"
```

### 3. Guardar y salir de vim
Presiona `Esc`, escribe `:wq` o `x`, y presiona `Enter`.

### 4. Hacer ejecutable el script
```bash
chmod +x script.sh
```

### 5. Ejecutar el script
```bash
./script.sh
```

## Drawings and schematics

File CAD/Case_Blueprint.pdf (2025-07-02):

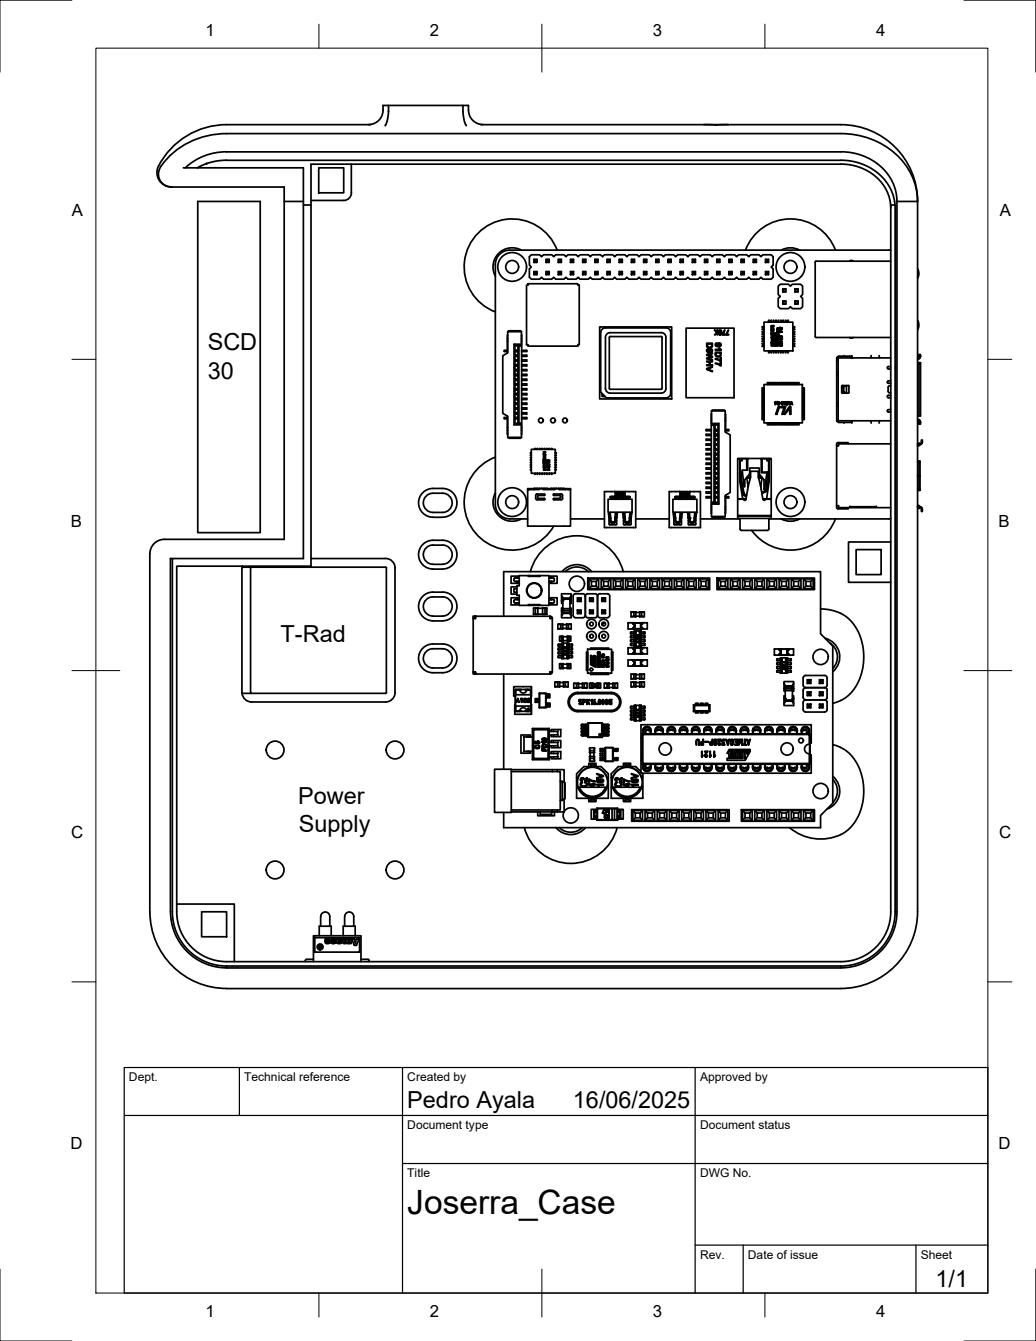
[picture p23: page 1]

Dept. | Technical reference | Created by Pedro Ayala 16/06/2025 | Approved by

Document type | Document status

Title Joserra_Case | DWG No.

Rev. | Date of issue | Sheet 1/1

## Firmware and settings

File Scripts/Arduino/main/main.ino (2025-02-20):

#include <WiFiNINA.h>
#include <PubSubClient.h>

// Definiciones para la red WiFi y ThingsBoard
#define WIFI_AP "IER"          
#define WIFI_PASSWORD "acadier2014" 
#define TOKEN "bXQq1eepFYJV3nldvLTV"
#define THINGSBOARD_SERVER "tb.ier.unam.mx"
#define MQTT_PORT 1883

// Inicialización de las librerías y objetos
WiFiClient espClient;
PubSubClient mqttClient(espClient);

/**
 * Configuración inicial del dispositivo.
 * Configura la conexión WiFi y el cliente MQTT para ThingsBoard.
 */
void setup() {
  WiFi.begin(WIFI_AP, WIFI_PASSWORD);  // Conectar a la red WiFi
  while (WiFi.status() != WL_CONNECTED) {
    delay(500);  // Espera hasta conectarse
  }
  
  mqttClient.setServer(THINGSBOARD_SERVER, MQTT_PORT);
  connectToThingsBoard();  // Conectar a ThingsBoard
}

/**
 * Ciclo principal del programa.
 * Mantiene las conexiones y realiza las tareas periódicas.
 */
void loop() {
  if (WiFi.status() != WL_CONNECTED) {
    reconnectWiFi();  // Reconecta WiFi si es necesario
  }
  
  if (!mqttClient.connected()) {
    reconnectThingsBoard();  // Reconecta MQTT si es necesario
  }

  // Obtener las mediciones de los termopares (temperaturas)
  float* temperatures = ThermocoupleTemp();
  sendTC(temperatures);    // Enviar temperaturas a ThingsBoard

  // Obtener la temperatura del TPF1
  float radiant = TPF1Temp();
  sendRT(radiant);  // Enviar temperatura radiante a ThingsBoard

  // Obtener la velocidad promedio del viento
  float* windspeed = WindSensor();
  sendWS(windspeed);      // Enviar velocidad del viento a ThingsBoard

  mqttClient.loop();
  delay(2000);  // Espera 2 segundos antes de la siguiente iteración
}

/**
 * Conecta a la red WiFi.
 */
void connectWiFi() {
  WiFi.begin(WIFI_AP, WIFI_PASSWORD);
  while (WiFi.status() != WL_CONNECTED) {
    delay(500);  // Espera hasta conectarse
  }
}

/**
 * Reconecta a la red WiFi si es necesario.
 */
void reconnectWiFi() {
  while (WiFi.status() != WL_CONNECTED) {
    WiFi.begin(WIFI_AP, WIFI_PASSWORD);
    delay(500);
  }
}

/**
 * Reconecta a ThingsBoard si es necesario.
 */
void reconnectThingsBoard() {
  while (!mqttClient.connected()) {
    connectToThingsBoard();
    delay(5000);  // Espera antes de reintentar
  }
}

/**
 * Conecta a ThingsBoard usando el token de autenticación.
 */
bool connectToThingsBoard() {
  return mqttClient.connect("ArduinoClient", TOKEN, NULL);
}

/**
 * Envía los datos de temperatura.
 */
void sendTC(float* temperatures) {
  String topic = "v1/devices/me/telemetry";
  String payload = "{\"T1\":" + String(temperatures[0]) + 
                   ", \"T2\":" + String(temperatures[1]) + 
                   ", \"T3\":" + String(temperatures[2]) + 
                   ", \"T4\":" + String(temperatures[3]) + "}";
  mqttClient.publish(topic.c_str(), payload.c_str());
}

/**
 * Envía los datos de temperatura radiante.
 */
void sendRT(float radiant) {
  String topic = "v1/devices/me/telemetry";
  String payload = "{\"TR\":" + String(radiant) + "}";
  mqttClient.publish(topic.c_str(), payload.c_str());  
}

/**
 * Envía los datos de velocidad del viento.
 */
void sendWS(float* windspeed) {
  String topic = "v1/devices/me/telemetry";
  String payload = "{\"WS\":" + String(windspeed[0]) + 
                   ", \"TEMP\":" + String(windspeed[1]) + "}";
  mqttClient.publish(topic.c_str(), payload.c_str());
}

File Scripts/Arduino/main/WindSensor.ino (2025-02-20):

#include <math.h>

const int OutPin  = A0;   // Pin analógico para el sensor de viento ("OUT")
const int TempPin = A2;   // Pin analógico para el sensor de temperatura ("TMP")

// Función que lee velocidad de viento y temperatura, y retorna un array de dos floats:
// ws[0] -> velocidad de viento (m/s)
// ws[1] -> temperatura (°C)
float* WindSensor() {
  static float ws[2];
  
  // Lectura del sensor de viento
  int windADunits = analogRead(OutPin);
  float voltage = (float)windADunits * 5.0 / 1024.0;
  
  // Aplicar la corrección al voltaje
  float correctedVoltage = voltage - 1.1621;
  
  // Lectura del sensor de temperatura
  int tempRawAD = analogRead(TempPin);
  float tempC = ((((float)tempRawAD * 5.0) / 1024.0) - 0.400) / 0.0195;
  
  // Cálculo de la velocidad de viento en m/s usando la ecuación empírica:
  // WS = 26.3431 * (correctedVoltage)^(1.4273) * (tempC)^(-0.7631)
  float windSpeed = 26.3431 * pow(correctedVoltage, 1.4273) * pow(tempC, -0.7631);
  
  ws[0] = windSpeed;
  ws[1] = tempC;
  
  return ws;
}

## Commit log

2024-09-12 Publish ThingsBoard via Arduino
2024-09-14 Add files via upload
    Publish ThingsBoard via Arduino
2025-06-04 Actualizción de scripts
2025-07-02 Agregué case
    [4xPowerSupply_Pin.3mf, 4xPowerSupply_Pin.step, 4xPowerSupply_Pin.stl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]
2025-08-28 Change communication protocol for several sensors
